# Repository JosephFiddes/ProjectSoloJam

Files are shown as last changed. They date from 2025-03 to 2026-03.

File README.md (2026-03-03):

# ProjectSoloJam (Work In Progress)
 Files and info for my solo jam project.

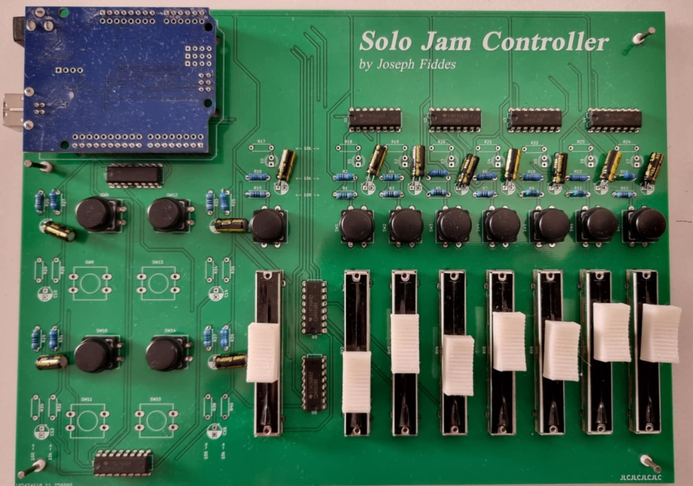
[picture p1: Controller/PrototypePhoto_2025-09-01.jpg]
Controller Prototype.


Physical controller to send commands to REAPER, via Open Sound Control. The controller can toggle recording, change track volumes, and set record arming for tracks.

A template REAPER project set up for the controller is found under SoloJamTemplate/SoloJamTemplate.rpp.

## Assembly
Solder the electronic components to the PCB. Note the Arduino UNO is connected via header pins.

Place four of Corner Washer Thing 1 on the piece of wood, and then place the PCB on top, such that the washers are going through the PCB's four corner holes (note: the top-left corner hole is underneath the Arduino UNO - see the image above).

Nail the PCB to the wood piece using nails with a 3mm diameter.

(optional) Place Corner Washer Thing 2 on each of the nails.

## Setup
### Dependencies
Currently, the solution is only designed for Windows.

The following dependencies are required:
 - [oscpp](https://github.com/kaoskorobase/oscpp): library for constructing and parsing OpenSoundControl packets.
 - windows.h

### Compilation

#### Serial2OSC

Prior to compilation, make sure that the port being used by the Arduino matches to port used by Serial2OSC. This can be done by opening serial2osc.cpp, finding the line `#define SERIAL_PORT "COM7"` and changing the `"COM7"` to whatever port the Arduino is using.

This project makes use of the winsock2.h library, and is compiled with MinGW (`g++`). Run `build` to compile the program.

#### Controller
The code for the controller is run on an Arduino UNO, and can be compiled in the Arduino IDE. The electrical circuit diagram of the controller is shown below:

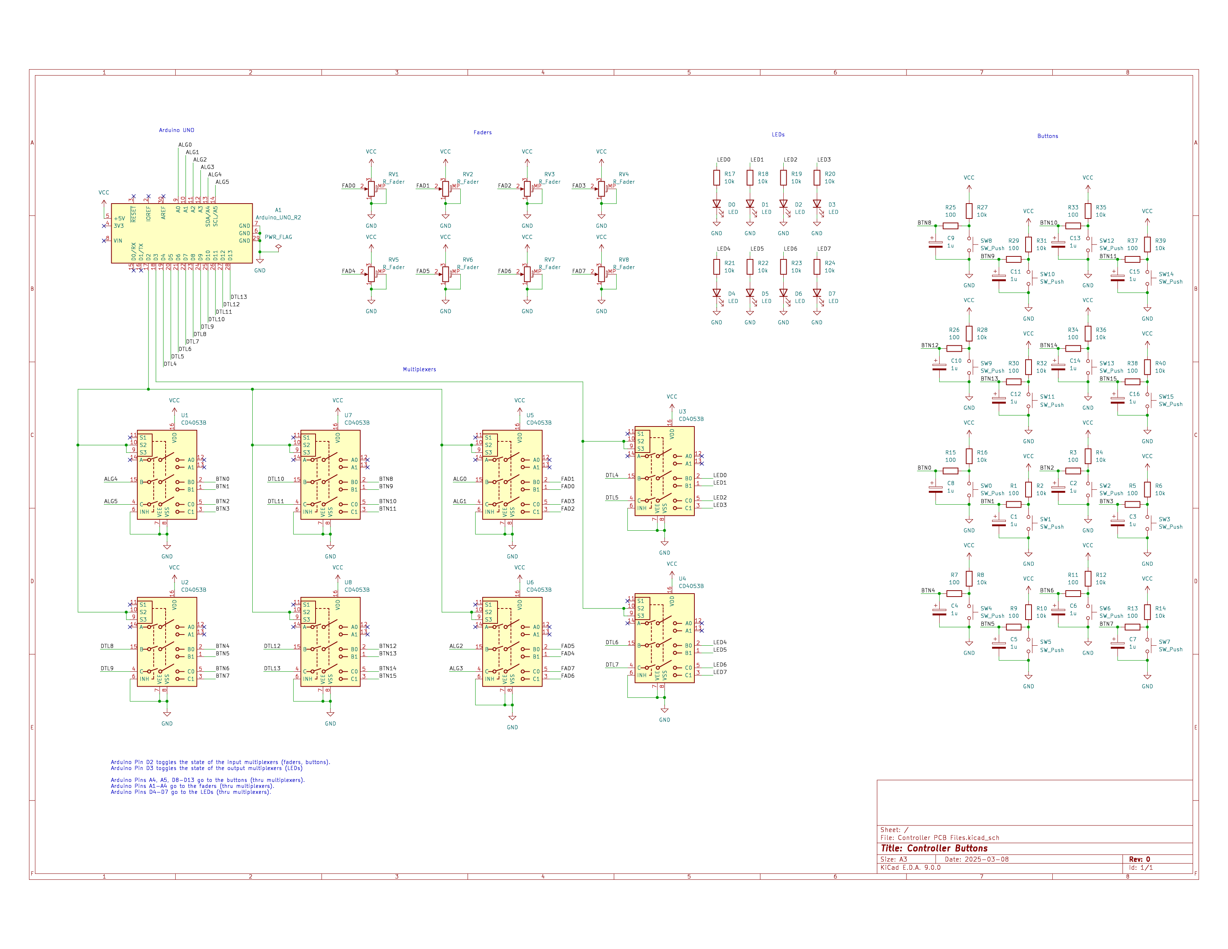
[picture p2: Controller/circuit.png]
Circuit diagram of controller.


A higher quality version of the image above may be found by [clicking here](./Controller/Controller%20PCB%20Files/Controller%20Schematic.pdf).

### Required REAPER Settings
REAPER needs to have OSC control enabled. 

1. Go to Preferences -> Control/OSC/Web. 
2. Add "OSC (Open Sound Control)" Control surface, with mode "Local port"
3. Set Local listen port to `2345`.

## Operation

With REAPER open, run serial2osc.exe. Pressing a button activates record arm for the corresponding track, and deactivates the record arm for the previous track.

## Bill of Materials

| Product | Qty  |
| --- | ---: |
| **Electronic Components:** | |
| FSM103 12x12mm switch  | 16 |
| AKTSC22K switch covers | 16 |
| Arduino Uno | 1 |
| PTA4553-2010CIB103 Slide Potentiometer | 8 |
| CD4053B Multiplexers | 8 |
| 1 uF Capacitors | 16 |
| 100 Ohm Resistors | 16 |
| 10K Ohm Resistors | 24 |
| 8-long row of Header Pins | 3 |
| 6-long row of Header Pins | 1 |
| Solo Jam Controller PCB | 1 |
| Piece of wood big enough to nail the PCB to | 1 |
| 3mm diameter nails | 4 |
| **3D Printed Files:** | |
| Corner Washer Thing 1 | 4 |
| Corner Washer Thing 2 | 4 |
| SliderKnob | 8 |

## TODO
 - Features to add to controller:
   - move playhead to start
   - Remove items from particular track
   - Edit tempo?
 - When recording starts while playback is off, playback turns on automatically - but the controller does not update bIsRecording. Also consider when playback turns off while recording, which leads to a wierd state.
 - Figure out bug where random nonsense sometimes gets sent through COM port on start-up. (low priority - hasn't happened in a while, and not a massive concern anyway)
 - In OSCconnection.h, find a way to force "buffer" to be aligned to 32 bits. (Note that the solution is to have it be the first thing in the class definition, but a better solution might be worthwhile since the current one doesn't feel super robust.)
 - Design and manufacture top-piece for controller for stability and isolation of electronics.

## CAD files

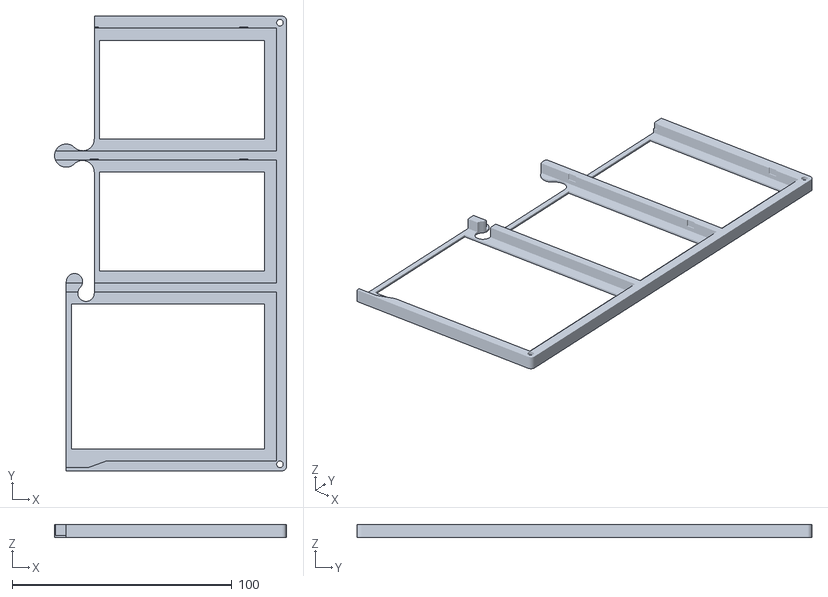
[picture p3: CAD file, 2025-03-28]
Controller/3d files/Base Plate Part 2.stl
105.6 x 207.0 x 6.00

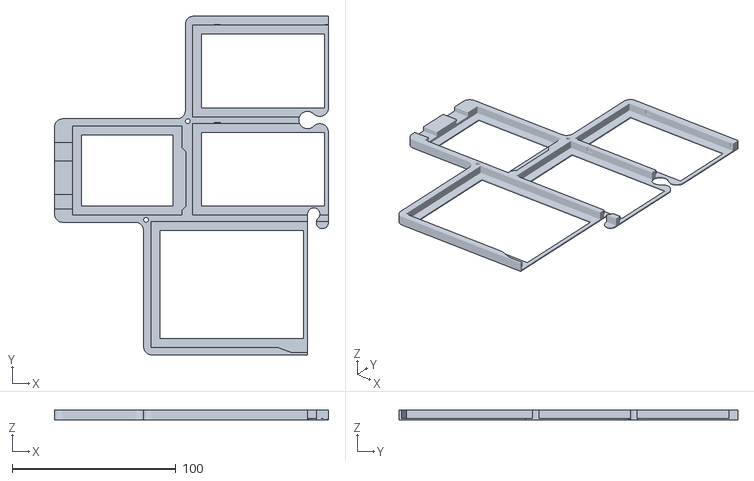
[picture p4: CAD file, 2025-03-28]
Controller/3d files/Base Plate Part 1.stl
167.4 x 207.0 x 6.00

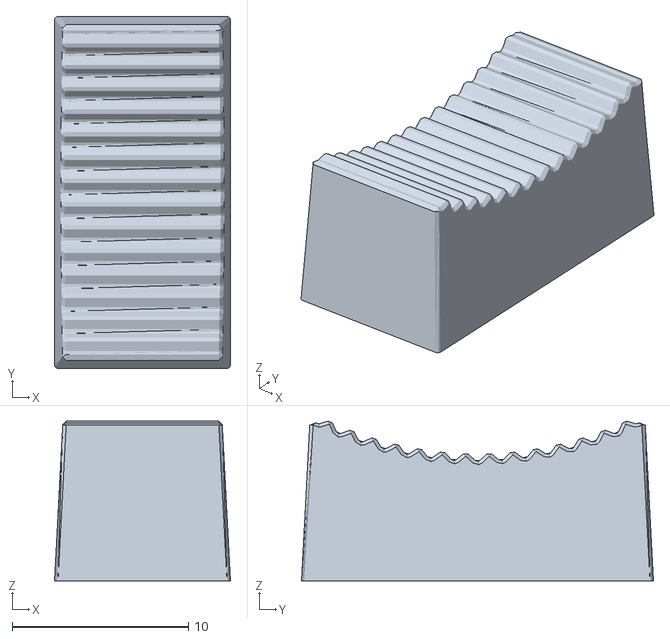
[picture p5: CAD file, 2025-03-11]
Controller/3d files/SliderKnob.stl
10.0 x 20.0 x 9.08

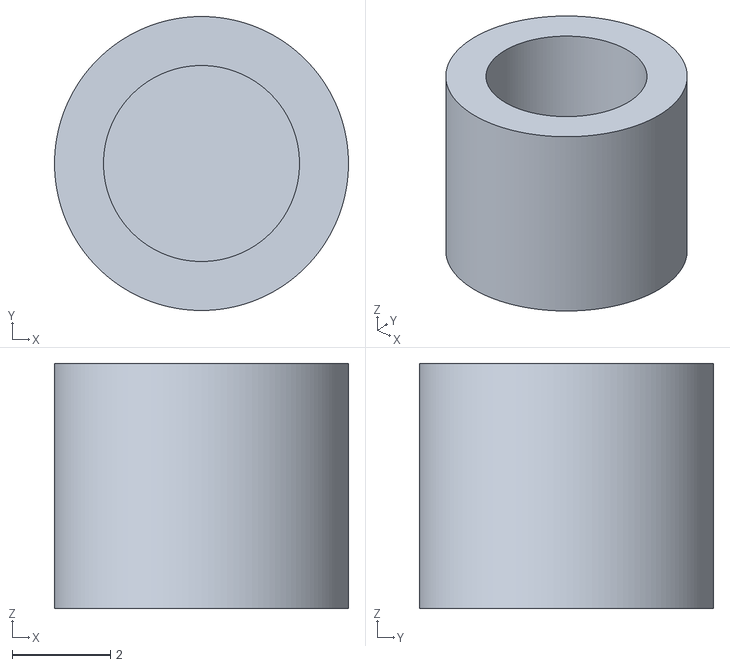
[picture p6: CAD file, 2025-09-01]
Controller/3d files/Corner Washer Thing 1.stl
6.00 x 6.00 x 5.00

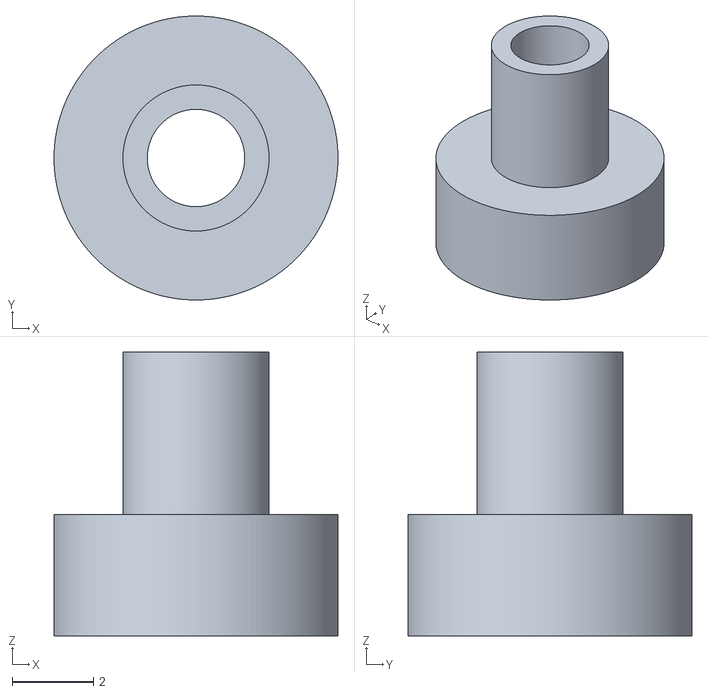
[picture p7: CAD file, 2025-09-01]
Controller/3d files/Corner Washer Thing 2.stl
7.00 x 7.00 x 7.00

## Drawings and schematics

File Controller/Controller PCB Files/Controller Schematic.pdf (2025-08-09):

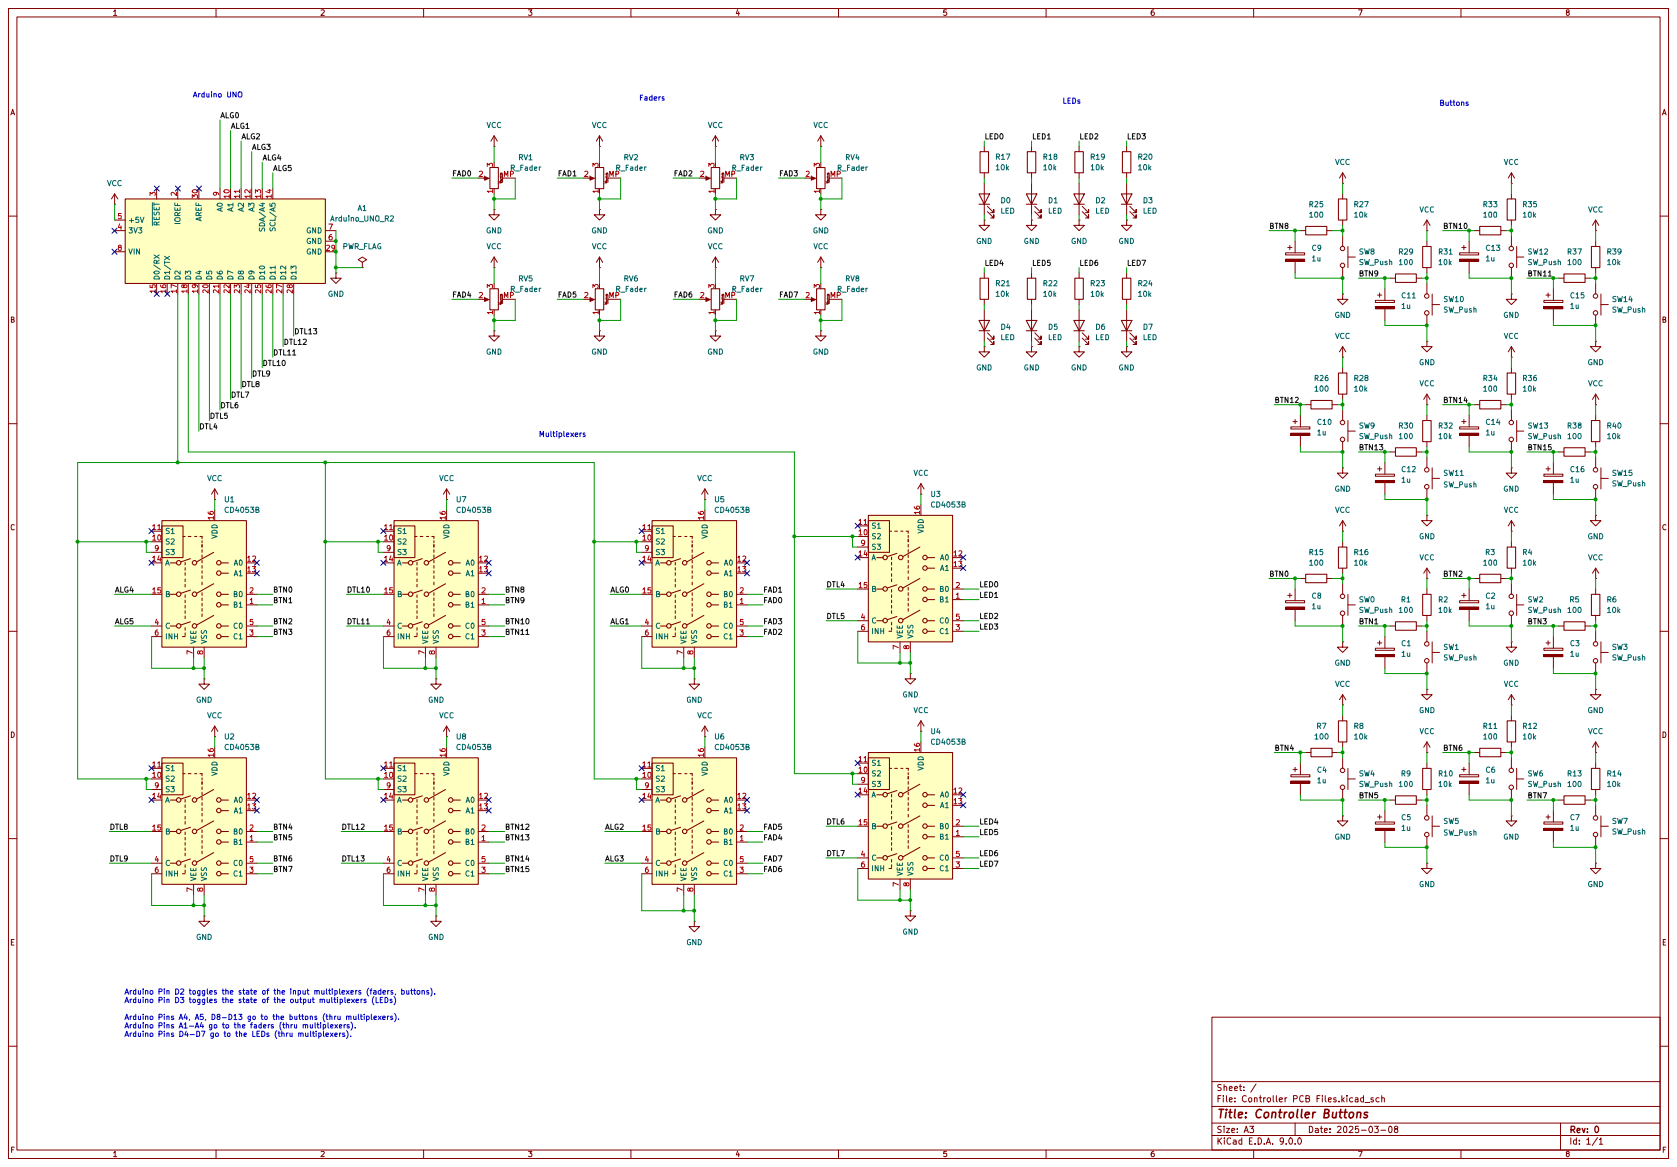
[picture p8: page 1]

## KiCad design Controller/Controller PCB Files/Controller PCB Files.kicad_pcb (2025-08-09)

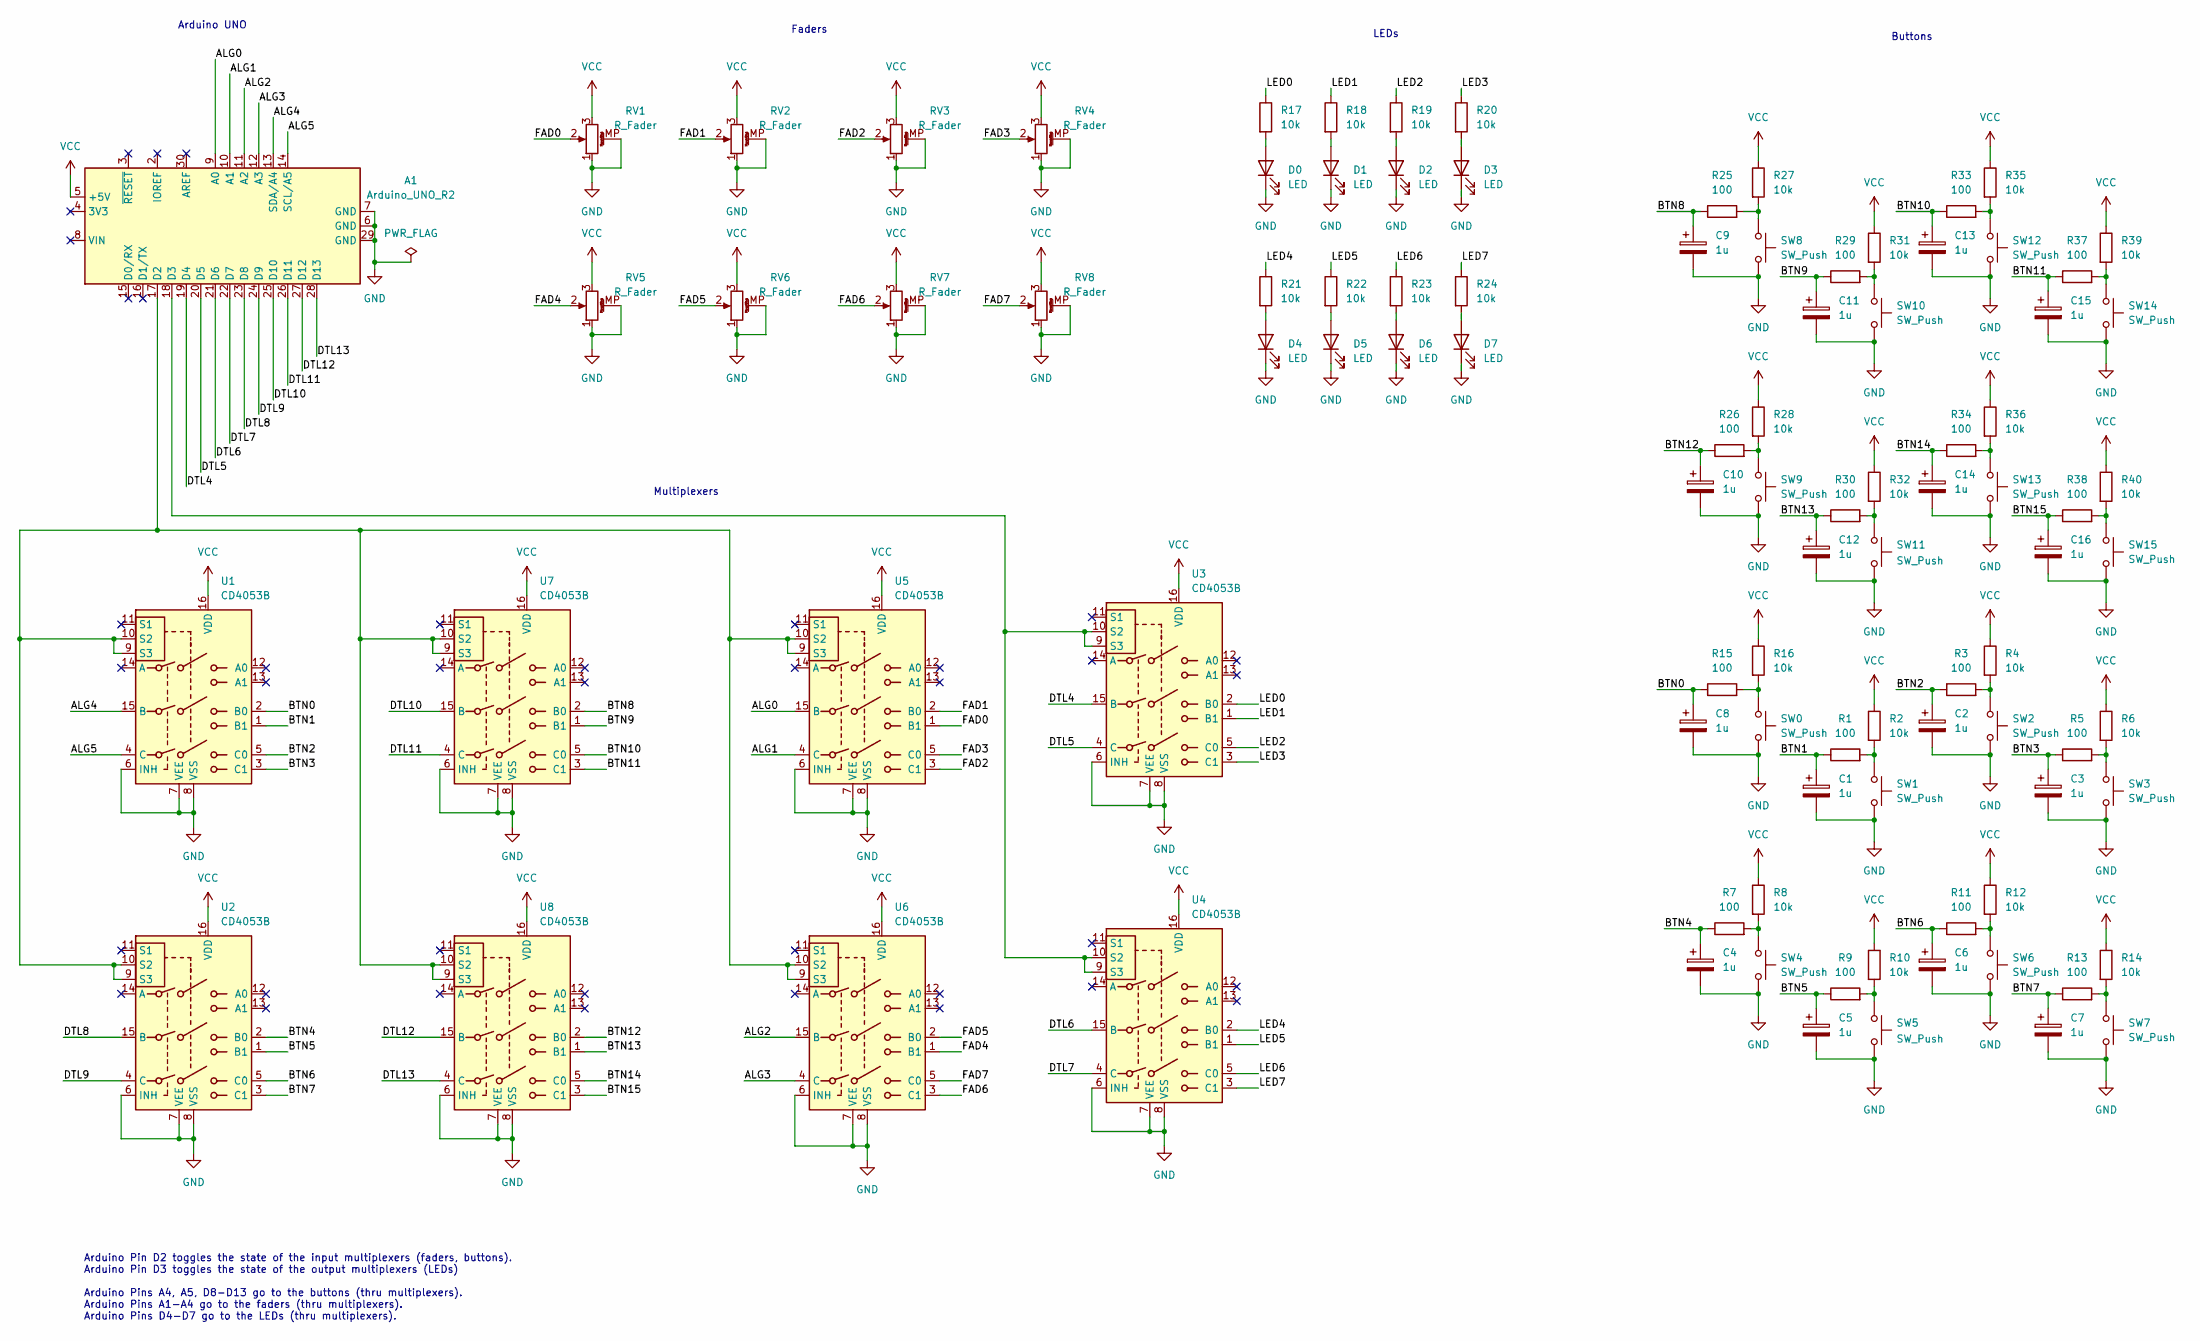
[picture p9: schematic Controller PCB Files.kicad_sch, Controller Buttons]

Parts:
A1: Arduino_UNO_R2; Arduino_UNO_R2_WithMountingHoles
C1, C2, C3, C4, C5, C6, C7, C8, C9, C10, C11, C12, C13, C14, C15, C16: 1u; CP_Radial_D5.0mm_P2.50mm
D0, D1, D2, D3, D4, D5, D6, D7: LED; LED_D4.0mm
R1, R3, R5, R7, R9, R11, R13, R15, R25, R26, R29, R30, R33, R34, R37, R38: 100; R_Axial_DIN0207_L6.3mm_D2.5mm_P7.62mm_Horizontal
R2, R4, R6, R8, R10, R12, R14, R16, R17, R18, R19, R20, R21, R22, R23, R24, R27, R28, R31, R32, R35, R36, R39, R40: 10k; R_Axial_DIN0207_L6.3mm_D2.5mm_P7.62mm_Horizontal
RV1, RV2, RV3, RV4, RV5, RV6, RV7, RV8: R_Fader; Potentiometer_Bourns_PTA4543_Single_Slide
SW0, SW1, SW2, SW3, SW4, SW5, SW6, SW7, SW8, SW9, SW10, SW11, SW12, SW13, SW14, SW15: SW_Push; SW_PUSH-12mm
U1, U2, U3, U4, U5, U6, U7, U8: CD4053B; DIP-16_W7.62mm

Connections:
/ALG0: A1.9 (A0), U5.15 (B)
/ALG1: A1.10 (A1), U5.4 (C)
/ALG2: A1.11 (A2), U6.15 (B)
/ALG3: A1.12 (A3), U6.4 (C)
/ALG4: A1.13 (SDA/A4), U1.15 (B)
/ALG5: A1.14 (SCL/A5), U1.4 (C)
/BTN0: C8.1, R15.1, U1.2 (B0)
/BTN1: C1.1, R1.1, U1.1 (B1)
/BTN2: C2.1, R3.1, U1.5 (C0)
/BTN3: C3.1, R5.1, U1.3 (C1)
/BTN4: C4.1, R7.1, U2.2 (B0)
/BTN5: C5.1, R9.1, U2.1 (B1)
/BTN6: C6.1, R11.1, U2.5 (C0)
/BTN7: C7.1, R13.1, U2.3 (C1)
/BTN8: C9.1, R25.1, U7.2 (B0)
/BTN9: C11.1, R29.1, U7.1 (B1)
/BTN10: C13.1, R33.1, U7.5 (C0)
/BTN11: C15.1, R37.1, U7.3 (C1)
/BTN12: C10.1, R26.1, U8.2 (B0)
/BTN13: C12.1, R30.1, U8.1 (B1)
/BTN14: C14.1, R34.1, U8.5 (C0)
/BTN15: C16.1, R38.1, U8.3 (C1)
/DTL4: A1.19 (D4), U3.15 (B)
/DTL5: A1.20 (D5), U3.4 (C)
/DTL6: A1.21 (D6), U4.15 (B)
/DTL7: A1.22 (D7), U4.4 (C)
/DTL8: A1.23 (D8), U2.15 (B)
/DTL9: A1.24 (D9), U2.4 (C)
/DTL10: A1.25 (D10), U7.15 (B)
/DTL11: A1.26 (D11), U7.4 (C)
/DTL12: A1.27 (D12), U8.15 (B)
/DTL13: A1.28 (D13), U8.4 (C)
/FAD0: RV1.2, U5.1 (B1)
/FAD1: RV2.2, U5.2 (B0)
/FAD2: RV3.2, U5.3 (C1)
/FAD3: RV4.2, U5.5 (C0)
/FAD4: RV5.2, U6.1 (B1)
/FAD5: RV6.2, U6.2 (B0)
/FAD6: RV7.2, U6.3 (C1)
/FAD7: RV8.2, U6.5 (C0)
/LED0: R17.1, U3.2 (B0)
/LED1: R18.1, U3.1 (B1)
/LED2: R19.1, U3.5 (C0)
/LED3: R20.1, U3.3 (C1)
/LED4: R21.1, U4.2 (B0)
/LED5: R22.1, U4.1 (B1)
/LED6: R23.1, U4.5 (C0)
/LED7: R24.1, U4.3 (C1)
GND: A1.6 (GND), A1.7 (GND), A1.29 (GND), C1.2, C2.2, C3.2, C4.2, C5.2, C6.2, C7.2, C8.2, C9.2, C10.2, C11.2, C12.2, C13.2, C14.2, C15.2, C16.2, D0.1 (K), D1.1 (K), D2.1 (K), D3.1 (K), D4.1 (K), D5.1 (K), D6.1 (K), D7.1 (K), RV1.1, RV1.MP (MountPin), RV2.1, RV2.MP (MountPin), RV3.1, RV3.MP (MountPin), RV4.1, RV4.MP (MountPin), RV5.1, RV5.MP (MountPin), RV6.1, RV6.MP (MountPin), RV7.1, RV7.MP (MountPin), RV8.1, RV8.MP (MountPin), SW0.2, SW1.2, SW2.2, SW3.2, SW4.2, SW5.2, SW6.2, SW7.2, SW8.2, SW9.2, SW10.2, SW11.2, SW12.2, SW13.2, SW14.2, SW15.2, U1.6 (INH), U1.7 (VEE), U1.8 (VSS), U2.6 (INH), U2.7 (VEE), U2.8 (VSS), U3.6 (INH), U3.7 (VEE), U3.8 (VSS), U4.6 (INH), U4.7 (VEE), U4.8 (VSS), U5.6 (INH), U5.7 (VEE), U5.8 (VSS), U6.6 (INH), U6.7 (VEE), U6.8 (VSS), U7.6 (INH), U7.7 (VEE), U7.8 (VSS), U8.6 (INH), U8.7 (VEE), U8.8 (VSS)
unnamed: A1.17 (D2), U1.9 (S3), U1.10 (S2), U2.9 (S3), U2.10 (S2), U5.9 (S3), U5.10 (S2), U6.9 (S3), U6.10 (S2), U7.9 (S3), U7.10 (S2), U8.9 (S3), U8.10 (S2)
unnamed: A1.18 (D3), U3.9 (S3), U3.10 (S2), U4.9 (S3), U4.10 (S2)
unnamed: D0.2 (A), R17.2
unnamed: D1.2 (A), R18.2
unnamed: D2.2 (A), R19.2
unnamed: D3.2 (A), R20.2
unnamed: D4.2 (A), R21.2
unnamed: D5.2 (A), R22.2
unnamed: D6.2 (A), R23.2
unnamed: D7.2 (A), R24.2
unnamed: R1.2, R2.2, SW1.1
unnamed: R3.2, R4.2, SW2.1
unnamed: R5.2, R6.2, SW3.1
unnamed: R7.2, R8.2, SW4.1
unnamed: R9.2, R10.2, SW5.1
unnamed: R11.2, R12.2, SW6.1
unnamed: R13.2, R14.2, SW7.1
unnamed: R15.2, R16.2, SW0.1
unnamed: R25.2, R27.2, SW8.1
unnamed: R26.2, R28.2, SW9.1
unnamed: R29.2, R31.2, SW10.1
unnamed: R30.2, R32.2, SW11.1
unnamed: R33.2, R35.2, SW12.1
unnamed: R34.2, R36.2, SW13.1
unnamed: R37.2, R39.2, SW14.1
unnamed: R38.2, R40.2, SW15.1
VCC: A1.5 (+5V), R2.1, R4.1, R6.1, R8.1, R10.1, R12.1, R14.1, R16.1, R27.1, R28.1, R31.1, R32.1, R35.1, R36.1, R39.1, R40.1, RV1.3, RV2.3, RV3.3, RV4.3, RV5.3, RV6.3, RV7.3, RV8.3, U1.16 (VDD), U2.16 (VDD), U3.16 (VDD), U4.16 (VDD), U5.16 (VDD), U6.16 (VDD), U7.16 (VDD), U8.16 (VDD)

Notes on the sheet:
Buttons
LEDs
Arduino Pin D2 toggles the state of the input multiplexers (faders, buttons). Arduino Pin D3 toggles the state of the output multiplexers (LEDs) Arduino Pins A4, A5, D8-D13 go to the buttons (thru multiplexers). Arduino Pins A1-A4 go to the faders (thru multiplexers). Arduino Pins D4-D7 go to the L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
Multiplexers
Arduino UNO
Faders

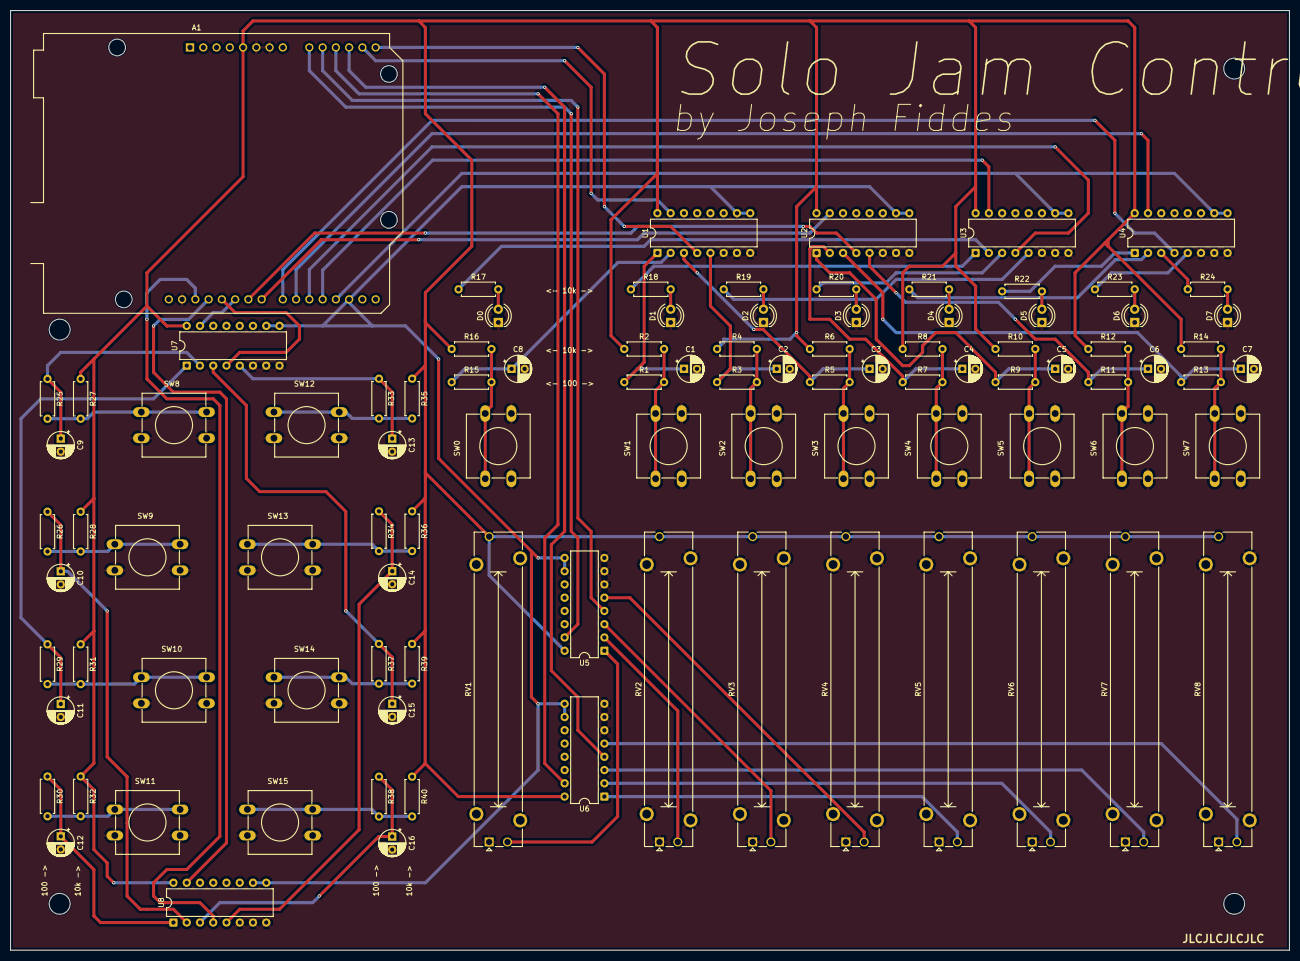
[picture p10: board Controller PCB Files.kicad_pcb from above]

Board: 4 copper layers, 245.0 x 180.0 mm, 97 parts (0 on the bottom side), 76 nets.

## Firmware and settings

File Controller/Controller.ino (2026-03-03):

#include <Arduino.h>
#include "toggle_buttons.h"
#include "sliders.h"

inline void update_values(bool digital_in[], const uint8_t total_digital_in,
  const uint8_t digital_in_pins[], const uint8_t total_digital_in_pins,
  int analog_in[], const uint8_t total_analog_in,
  const uint8_t analog_in_pins[], const uint8_t total_analog_in_pins,
  const uint8_t mux_toggle_pin); 

// Pin designations:
#define SENSOR_MUX_TOGGLE_PIN 2
#define DISPLAY_MUX_TOGGLE_PIN 3

#define TOTAL_DIGITAL_IN_PINS 6
const uint8_t digital_in_pins[TOTAL_DIGITAL_IN_PINS] = {A4, A5, 8, 9, 10, 11};

#define TOTAL_ANALOG_IN_PINS 4
const uint8_t analog_in_pins[TOTAL_ANALOG_IN_PINS] = {A0, A1, A2, A3};

#define TOTAL_DIGITAL_IN_VALUES (TOTAL_DIGITAL_IN_PINS * 2)
#define TOTAL_ANALOG_IN_VALUES (TOTAL_ANALOG_IN_PINS * 2)

#define TOTAL_RECARM_BUTTONS 7

// Buttons for arming each track (note: all radio buttons)
Toggle_buttons track_recarm_buttons = Toggle_buttons(
  TOTAL_RECARM_BUTTONS, 1, false
);

#define TOTAL_RECORD_BUTTONS 1

// Button for toggling recording (note: check button)
Toggle_buttons record_buttons = Toggle_buttons(
  TOTAL_RECORD_BUTTONS, 0, false
);

#define TOTAL_MISC_FUNC_BUTTONS 4

// Miscellaneous function buttons
Toggle_buttons misc_func_buttons = Toggle_buttons(
  TOTAL_MISC_FUNC_BUTTONS, 0x100, false 
);

#define TOTAL_TRACK_VOL_SLIDERS 8

Sliders track_vol_sliders = Sliders(TOTAL_TRACK_VOL_SLIDERS, 0);

// Effects are applied PreFader, including ReaStream. Therefore we can't
// adjust the master fader directly.
// Instead, all tracks are sent to a "master track", which then sends its output
// post-fader to the real master track.
// #define TOTAL_MASTER_VOL_SLIDERS 1
// 
// Sliders master_vol_sliders = Sliders(
//   TOTAL_MASTER_VOL_SLIDERS,
//   "n/master/volume"
// );

bool* digital_in_values;
int* analog_in_values; 

void setup() {
  Serial.begin(9600);

  for (uint8_t i = 0; i<TOTAL_ANALOG_IN_PINS; i++) pinMode(analog_in_pins[i], INPUT);
  for (uint8_t i = 0; i<TOTAL_DIGITAL_IN_PINS; i++) pinMode(digital_in_pins[i], INPUT);

  pinMode(SENSOR_MUX_TOGGLE_PIN, OUTPUT);
  pinMode(DISPLAY_MUX_TOGGLE_PIN, OUTPUT);

  digital_in_values = (bool*) malloc(sizeof(bool)*TOTAL_DIGITAL_IN_VALUES);
  analog_in_values = (int*) malloc(sizeof(int)*TOTAL_ANALOG_IN_VALUES);
}

void loop() {
  update_values(digital_in_values, TOTAL_DIGITAL_IN_VALUES,
    digital_in_pins, TOTAL_DIGITAL_IN_PINS,
    analog_in_values, TOTAL_ANALOG_IN_VALUES,
    analog_in_pins, TOTAL_ANALOG_IN_PINS,
    SENSOR_MUX_TOGGLE_PIN);

/*
  for (uint8_t i = 0; i<TOTAL_DIGITAL_IN_VALUES; i++) {
    Serial.print(digital_in_values[i]);
    Serial.print(", ");
  }
  Serial.println();
  

  for (uint8_t i = 0; i<TOTAL_ANALOG_IN_VALUES; i++) {
    Serial.print(analog_in_values[i]);
    Serial.print(", ");
  }
  Serial.println();

  Serial.flush();
*/


  track_recarm_buttons.update(digital_in_values + 1);
  record_buttons.update(digital_in_values);
  misc_func_buttons.update(digital_in_values + 8);

  track_vol_sliders.update(analog_in_values);
  // master_vol_sliders.update(analog_in_values);

  // Add a delay between loops so the reader doesn't get filled up with too many similar commands during a fade.
  delay(55);
}

inline void update_values(bool digital_in[], const uint8_t total_digital_in,
  const uint8_t digital_in_pins[], const uint8_t total_digital_in_pins,
  int analog_in[], const uint8_t total_analog_in,
  const uint8_t analog_in_pins[], const uint8_t total_analog_in_pins,
  const uint8_t mux_toggle_pin) 
{
  // First pass MUX 1
  digitalWrite(mux_toggle_pin, 1);
  delayMicroseconds(1);

  uint8_t i;
  for (i=0; i < total_digital_in_pins; i++) {
    // MUX 1 affects odd digital inputs.
    digital_in[2*i + 1] = digitalRead(digital_in_pins[i]);
  }

  for (i=0; i < total_analog_in_pins; i++) {
    // MUX 1 affects even analog inputs. 
    analog_in[2*i] = analogRead(analog_in_pins[i]);
  }

  // Second pass MUX 0
  digitalWrite(mux_toggle_pin, 0);
  delayMicroseconds(1);

  for (i=0; i < total_digital_in_pins; i++) {
    // MUX 0 affects even digital inputs.
    digital_in[2*i] = digitalRead(digital_in_pins[i]);
  }

  for (i=0; i < total_analog_in_pins; i++) {
    // MUX 0 affects odd analog inputs. 
    analog_in[2*i + 1] = analogRead(analog_in_pins[i]);
  }
  
  // The mismatch of parity between digital and analog inputs is
  // not intentional, but I'll be damned if I have to redesign 
  // and solder another fucking PCB, so we're sticking with it.
}

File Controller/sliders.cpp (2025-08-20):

#include "sliders.h"

//#define DEBUG

#define SLIDER_THRESHOLD 20
#define NORM_FACTOR (1.0 / 1024)

Sliders::Sliders(uint8_t total_sliders, uint32_t first_index)
{
  // Allocate memory.
  this->values = (int*) calloc(total_sliders, sizeof(int));
  this->bToggled = (bool*) calloc(total_sliders, sizeof(bool));

  this->total_sliders = total_sliders;
  this->first_index = first_index;
}

void Sliders::update(int new_values[])
{
  update_sliders(new_values);
  send_to_outputs();  
}

inline void Sliders::update_sliders(int new_values[])
{
  int diff;

  // Check if slider has sufficiently changed.
  for (uint8_t i = 0; i < total_sliders; i++) {
    bToggled[i] = false;

    diff = abs(values[i] - new_values[i]);
    if (diff >= SLIDER_THRESHOLD) {
      bToggled[i] = true;
      values[i] = new_values[i];
    }
  }
}

inline void Sliders::send_to_outputs() 
{
  Binary_float normalized_value;

  for (uint8_t i=0; i < total_sliders; i++) {
    if (bToggled[i]) {
      // OSC expects 32-bit big-endian IEEE 754 floating point number 
      normalized_value.fvalue = values[i] * NORM_FACTOR;

      send_message(first_index + i, normalized_value);
    }
  }
}

inline void Sliders::send_message(const uint32_t index, const Binary_float value) {
  Serial.write('F');
  #ifdef DEBUG  
    Serial.print(index);
    Serial.print(value.fvalue);
    Serial.println();
  #else
    Serial.write((byte*) &index, 4);
    Serial.write((byte*) &(value.bits), 4);
    Serial.flush();
  #endif
}

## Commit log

2024-12-02 Toggle buttons implemented for hardware controller
2024-12-04 Radio-style buttons and serial write implemented
2024-12-10 Radio buttons successfully control REAPER.
2024-12-12 Added support for OSC "toggle" commands, and added button for toggling recording.
2025-03-28 Added support for sliders, and increased number of buttons
2025-03-28 Added Base plate, updated BOM
    [Base Plate Part 1.stl, Base Plate Part 2.stl]
2025-05-07 Track 1 now used as master track; ReaStream now reacts to master fader
2025-05-14 Allows choice of toggle on button up or button down. Defaults to button down
2025-05-14 Changing record arm stops recording
2025-08-09 Added controller PCB files and updated README with new controller schematic
    [Controller PCB Files.kicad_pcb, Controller PCB Files.kicad_sch]
2025-08-09 Update BoM and TODO list
2025-08-25 Updated controller to match with circuit board.
2025-09-01 PCB update. Added washer STLs and updated BoM & header image
    [Corner Washer Thing 1.stl, Corner Washer Thing 2.stl]
2025-11-26 Removed record-arm of first track (added accidentally in prev. commit)
2026-02-05 Added delete all items button, default arguments for add_to_buffer, and batch file for compilation
2026-03-03 Added delay to microcontroller so serial2osc isn't stuck waiting for a bunch of similar commands
    [Controller.ino]
